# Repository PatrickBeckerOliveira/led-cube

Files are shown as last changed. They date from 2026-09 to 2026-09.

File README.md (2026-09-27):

# LED Cube 4×4×4 — ESP32-C3 + BLE

A 64-LED cube controlled by an ESP32-C3 SuperMini, two daisy-chained TPIC6B595 shift registers, and four layers switched by NPN-driven P-channel MOSFETs. Arduino firmware with BLE commands and five sequential animation effects.

## Firmware

Open `led_cube_ble/led_cube_ble.ino` in the Arduino IDE with the **esp32 board package by Espressif Systems** installed. Select the appropriate ESP32-C3 board (ESP32C3 Dev Module where applicable) and serial port. The code uses the BLE library included in the ESP32 package, along with `<atomic>`.

This version preserves the behavior of the animation code provided in the conversation. It has not been compiled or validated on hardware as part of this delivery; no specific ESP32 board package version has been pinned.

## Pin Mapping

| Function | GPIO |
|---|---:|
| TPIC SER IN / Data | 4 |
| TPIC SRCK / Clock | 5 |
| TPIC RCK / Latch | 6 |
| Layer 1 / NPN base | 7 |
| Layer 2 / NPN base | 8 |
| Layer 3 / NPN base | 9 |
| Layer 4 / NPN base | 10 |

Driving a layer GPIO high turns on the NPN transistor, which in turn switches on the P-channel MOSFET. A bit set to 1 in the TPIC activates the corresponding current-sinking output. The physical column order depends on the wiring.

## Using nRF Connect

1. Power on the board and connect to `Cubo_LED_4x4x4`.
2. Open service `6e400001-b5a3-f393-e0a9-e50e24dcca9e`.
3. Write UTF-8 text to characteristic `6e400002-b5a3-f393-e0a9-e50e24dcca9e`.

| Command | Action |
|---|---|
| `ON` or `1` | Start/restart the sequence |
| `OFF` or `0` | Turn off the cube |

The cube starts with all LEDs off when powered on. Disconnecting the app does not stop an ongoing animation; the device resumes advertising to allow reconnection. Commands do not require BLE authentication.

## Effects

1. Layers moving up and down.
2. Vertical columns lighting up in sequence.
3. Eight twinkling points.
4. Filling and emptying the cube layer by layer.
5. Three flashes followed by a pause.

The sequence repeats until `OFF` is received. Animation updates use `millis()`, and multiplexing uses `micros()`, with a nominal period of 2 ms per layer and a blanking interval of 30 µs. At most one layer is activated at a time. Timing and duration can be adjusted through the constants and the `updateAnimation()` function.

## Hardware Notes

- Cube supply: 5 V, with a common ground shared with the ESP. The power supply's current rating does not determine the current capacity of the SuperMini's PCB traces.
- GPIO8 and GPIO9 are boot strapping pins. The NPN base connections may interfere with startup, especially on GPIO9; using 10 kΩ resistors connected to the base showed no problems, lowering this value may cause issues.
- According to its datasheet, a TPIC6B595 powered at 5 V requires a minimum logic-high input of 0.85 × VCC = 4.25 V. Direct drive from 3.3 V GPIOs works but is not guaranteed; logic-level conversion should be implemented in the future.
- With 100 Ω column resistors and an LED forward voltage of approximately 3 V, the simplified estimate is 20 mA per LED and 320 mA for a full layer, plus the control electronics. Measure the actual current before sizing the power supply.

References: [TPIC6B595 — TI](https://www.ti.com/lit/ds/symlink/tpic6b595.pdf), [ESP32-C3 Boot Mode Selection — Espressif](https://docs.espressif.com/projects/esptool/en/latest/esp32c3/advanced-topics/boot-mode-selection.html).

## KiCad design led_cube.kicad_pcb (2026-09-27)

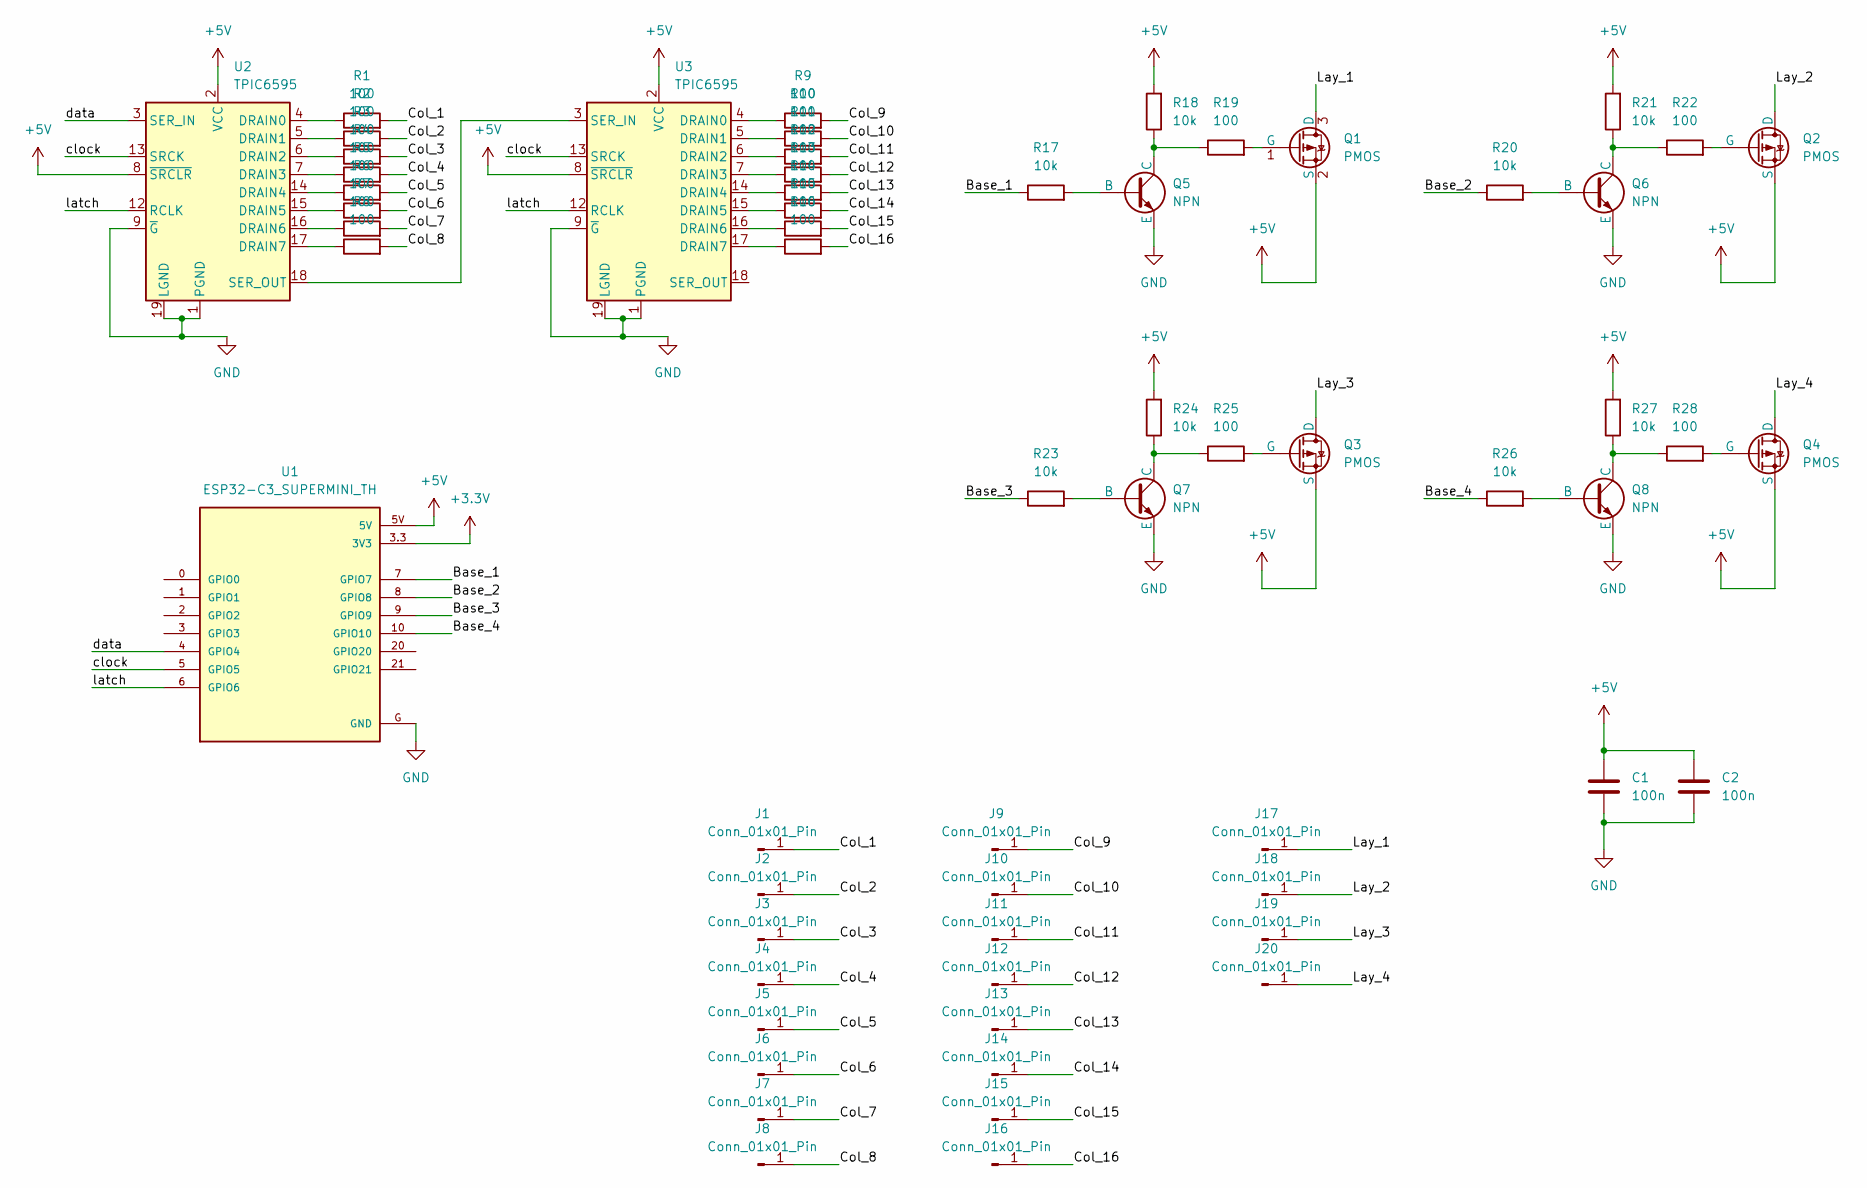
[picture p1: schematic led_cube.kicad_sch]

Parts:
C1, C2: 100n; C_Disc_D10.0mm_W2.5mm_P5.00mm
J1, J2, J3, J4, J5, J6, J7, J8, J9, J10, J11, J12, J13, J14, J15, J16, J17, J18, J19, J20: Conn_01x01_Pin; TestPoint_THTPad_3.0x3.0mm_Drill1.5mm
Q1, Q2, Q3, Q4: PMOS; SOT-23_Handsoldering
Q5, Q6, Q7, Q8: NPN; TO-92_HandSolder
R1, R2, R3, R4, R5, R6, R7, R8, R9, R10, R11, R12, R13, R14, R15, R16, R19, R22, R25, R28: 100; R_1206_3216Metric_Pad1.30x1.75mm_HandSolder
R17, R18, R20, R21, R23, R24, R26, R27: 10k; R_1206_3216Metric_Pad1.30x1.75mm_HandSolder
U1: ESP32-C3_SUPERMINI_TH; MODULE_ESP32-C3_SUPERMINI_TH
U2, U3: TPIC6595; CERDIP-20_W7.62mm_SideBrazed

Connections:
+3.3V: U1.3.3 (3V3)
+5V: C1.1, C2.1, Q1.2 (S), Q2.2 (S), Q3.2 (S), Q4.2 (S), R18.2, R21.2, R24.2, R27.2, U1.5V, U2.2 (VCC), U2.8 (~SRCLR), U3.2 (VCC), U3.8 (~SRCLR)
/Base_1: R17.1, U1.7 (GPIO7)
/Base_2: R20.1, U1.8 (GPIO8)
/Base_3: R23.1, U1.9 (GPIO9)
/Base_4: R26.1, U1.10 (GPIO10)
/Col_1: J1.1 (Pin_1_1), R1.2
/Col_2: J2.1 (Pin_1_1), R2.2
/Col_3: J3.1 (Pin_1_1), R3.2
/Col_4: J4.1 (Pin_1_1), R4.2
/Col_5: J5.1 (Pin_1_1), R5.2
/Col_6: J6.1 (Pin_1_1), R6.2
/Col_7: J7.1 (Pin_1_1), R7.2
/Col_8: J8.1 (Pin_1_1), R8.2
/Col_9: J9.1 (Pin_1_1), R9.2
/Col_10: J10.1 (Pin_1_1), R10.2
/Col_11: J11.1 (Pin_1_1), R11.2
/Col_12: J12.1 (Pin_1_1), R12.2
/Col_13: J13.1 (Pin_1_1), R13.2
/Col_14: J14.1 (Pin_1_1), R14.2
/Col_15: J15.1 (Pin_1_1), R15.2
/Col_16: J16.1 (Pin_1_1), R16.2
/Lay_1: J17.1 (Pin_1_1), Q1.3 (D)
/Lay_2: J18.1 (Pin_1_1), Q2.3 (D)
/Lay_3: J19.1 (Pin_1_1), Q3.3 (D)
/Lay_4: J20.1 (Pin_1_1), Q4.3 (D)
/clock: U1.5 (GPIO5), U2.13 (SRCK), U3.13 (SRCK)
/data: U1.4 (GPIO4), U2.3 (SER_IN)
/latch: U1.6 (GPIO6), U2.12 (RCLK), U3.12 (RCLK)
GND: C1.2, C2.2, Q5.3 (E), Q6.3 (E), Q7.3 (E), Q8.3 (E), U1.G (GND), U2.1 (PGND), U2.9 (~G), U2.10 (PGND), U2.11 (PGND), U2.19 (LGND), U2.20 (PGND), U3.1 (PGND), U3.9 (~G), U3.10 (PGND), U3.11 (PGND), U3.19 (LGND), U3.20 (PGND)
unnamed: Q1.1 (G), R19.2
unnamed: Q2.1 (G), R22.2
unnamed: Q3.1 (G), R25.2
unnamed: Q4.1 (G), R28.2
unnamed: Q5.2 (B), R17.2
unnamed: Q5.1 (C), R18.1, R19.1
unnamed: Q6.2 (B), R20.2
unnamed: Q6.1 (C), R21.1, R22.1
unnamed: Q7.2 (B), R23.2
unnamed: Q7.1 (C), R24.1, R25.1
unnamed: Q8.2 (B), R26.2
unnamed: Q8.1 (C), R27.1, R28.1
unnamed: R1.1, U2.4 (DRAIN0)
unnamed: R2.1, U2.5 (DRAIN1)
unnamed: R3.1, U2.6 (DRAIN2)
unnamed: R4.1, U2.7 (DRAIN3)
unnamed: R5.1, U2.14 (DRAIN4)
unnamed: R6.1, U2.15 (DRAIN5)
unnamed: R7.1, U2.16 (DRAIN6)
unnamed: R8.1, U2.17 (DRAIN7)
unnamed: U2.18 (SER_OUT), U3.3 (SER_IN)
unnamed: R9.1, U3.4 (DRAIN0)
unnamed: R10.1, U3.5 (DRAIN1)
unnamed: R11.1, U3.6 (DRAIN2)
unnamed: R12.1, U3.7 (DRAIN3)
unnamed: R13.1, U3.14 (DRAIN4)
unnamed: R14.1, U3.15 (DRAIN5)
unnamed: R15.1, U3.16 (DRAIN6)
unnamed: R16.1, U3.17 (DRAIN7)

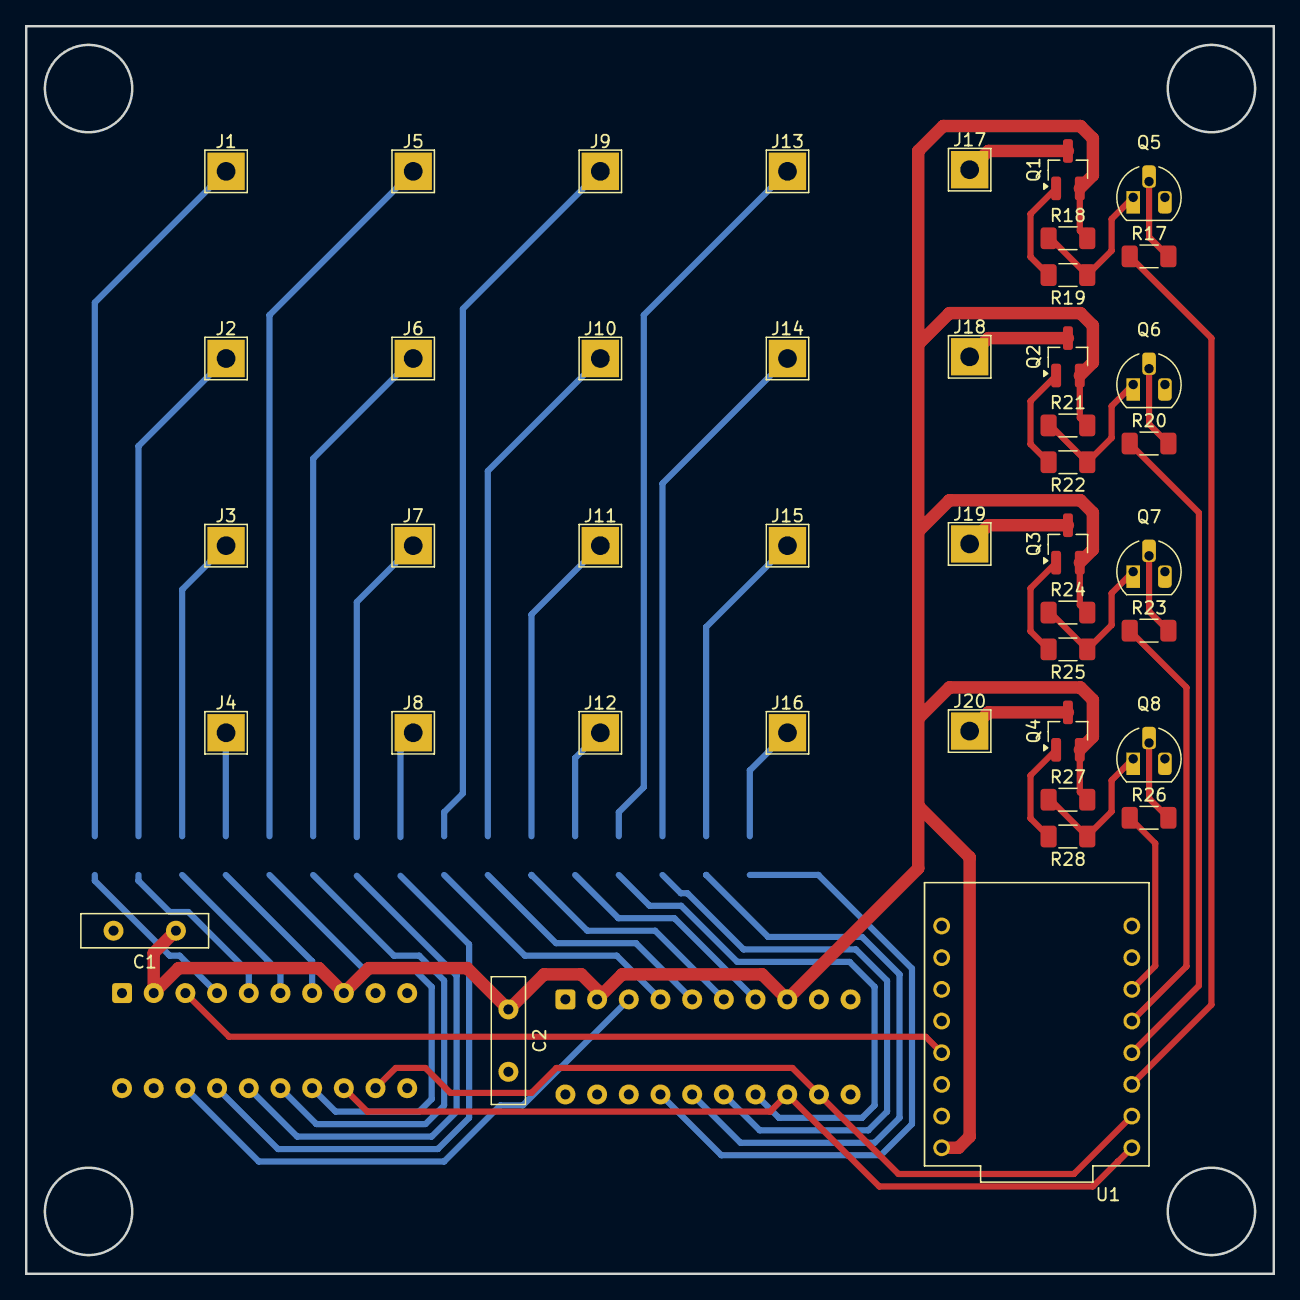
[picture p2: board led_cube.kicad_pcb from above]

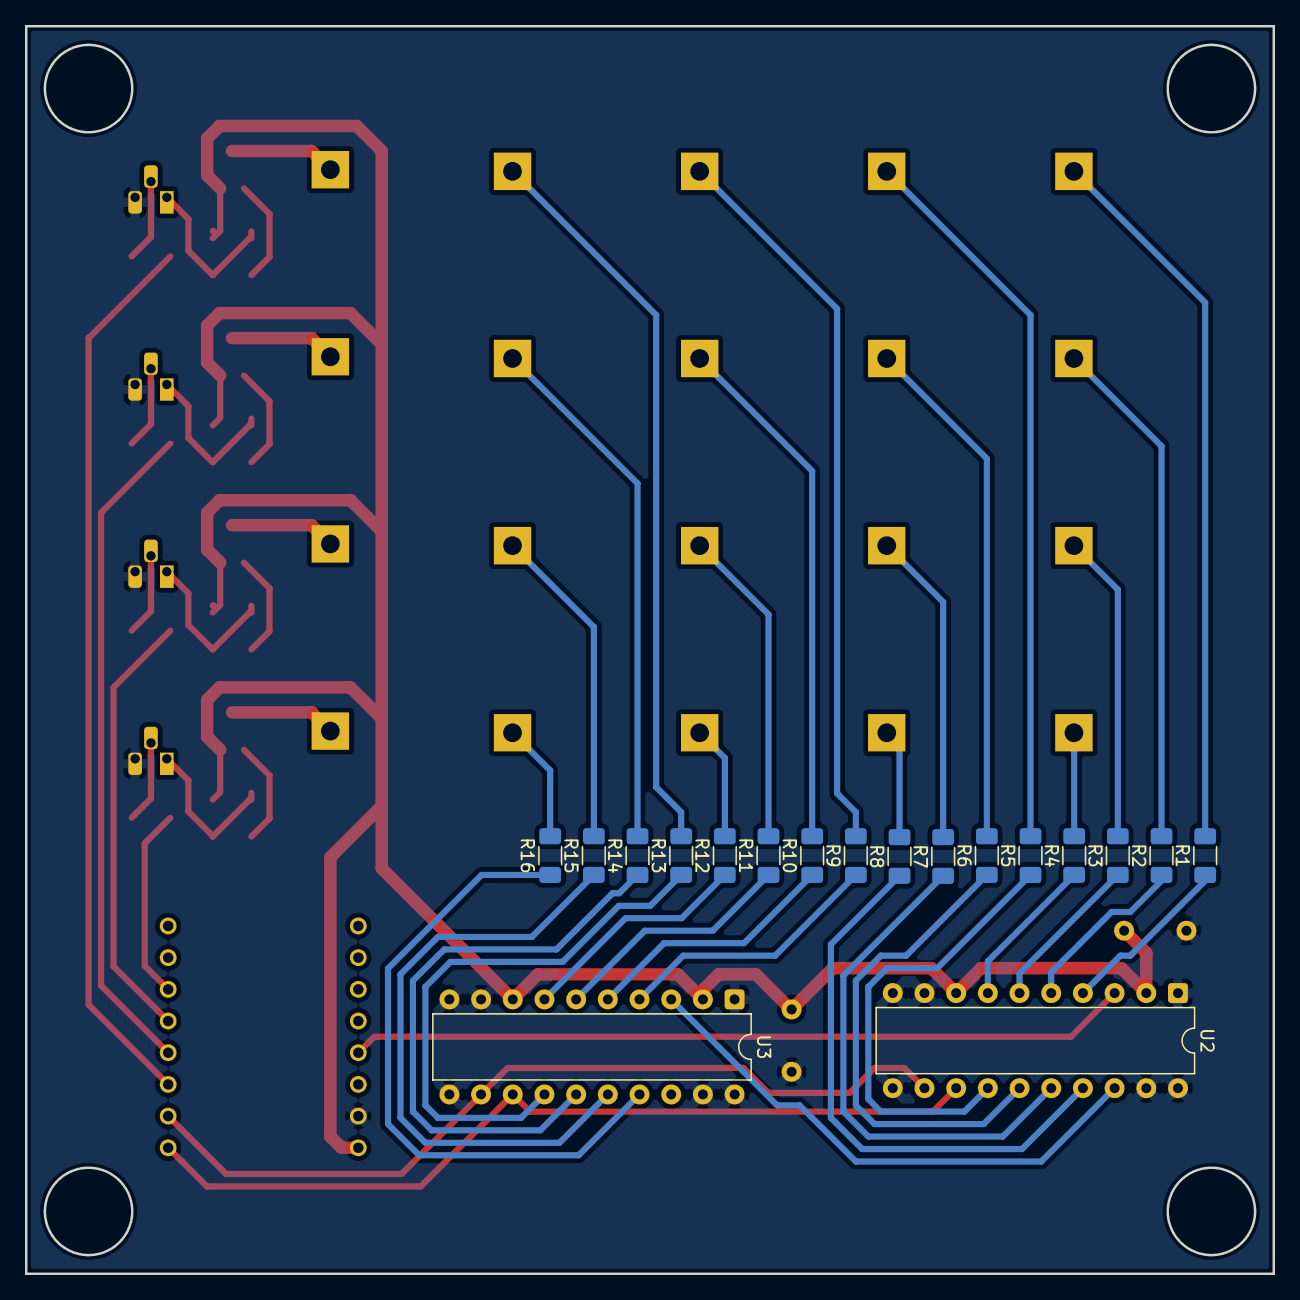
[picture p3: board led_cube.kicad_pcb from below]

Board: 2 copper layers, 100.0 x 100.0 mm, 61 parts (18 on the bottom side), 58 nets.

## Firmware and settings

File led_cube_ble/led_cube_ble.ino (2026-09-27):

#include <Arduino.h>
#include <BLEDevice.h>
#include <BLEServer.h>
#include <BLEUtils.h>
#include <atomic>

// Circuit pins for the ESP32-C3 and two TPIC6B595 shift registers.
constexpr uint8_t PIN_DATA = 4;
constexpr uint8_t PIN_CLOCK = 5;
constexpr uint8_t PIN_LATCH = 6;
constexpr uint8_t PIN_LAYER[4] = {7, 8, 9, 10};
constexpr uint32_t LAYER_TIME_US = 2000;
constexpr uint32_t BLANK_TIME_US = 30;

#define SERVICE_UUID "6e400001-b5a3-f393-e0a9-e50e24dcca9e"
#define COMMAND_UUID "6e400002-b5a3-f393-e0a9-e50e24dcca9e"

enum Command { CMD_NONE, CMD_ON, CMD_OFF };
std::atomic<int> pendingCommand{CMD_NONE};
std::atomic<bool> restartAdvertising{false};
bool cubeEnabled = false;

// One element per layer; each bit represents a column.
uint16_t frame[4] = {0, 0, 0, 0};
uint8_t scanLayer = 0;
uint32_t lastScanUs = 0;
uint8_t effect = 0;
uint32_t effectStartMs = 0;
uint32_t lastAnimationStep = UINT32_MAX;
const uint32_t EFFECT_DURATION_MS[] = {4200, 4800, 4000, 1800, 1500};
constexpr uint8_t EFFECT_COUNT =
  sizeof(EFFECT_DURATION_MS) / sizeof(EFFECT_DURATION_MS[0]);

void disableLayers() {
  for (uint8_t pin : PIN_LAYER) digitalWrite(pin, LOW);
}

void setColumns(uint16_t columns) {
  digitalWrite(PIN_LATCH, LOW);
  shiftOut(PIN_DATA, PIN_CLOCK, MSBFIRST, highByte(columns));
  shiftOut(PIN_DATA, PIN_CLOCK, MSBFIRST, lowByte(columns));
  digitalWrite(PIN_LATCH, HIGH);
}

void clearFrame() {
  for (uint8_t layer = 0; layer < 4; layer++) frame[layer] = 0;
}

void fillFrame() {
  for (uint8_t layer = 0; layer < 4; layer++) frame[layer] = 0xFFFF;
}

void turnCubeOff() {
  disableLayers();
  setColumns(0);
  clearFrame();
}

void refreshCube() {
  const uint32_t nowUs = micros();
  if (nowUs - lastScanUs < LAYER_TIME_US) return;
  lastScanUs = nowUs;
  // Blank the outputs before switching layers to prevent overlap.
  disableLayers();
  setColumns(0);
  delayMicroseconds(BLANK_TIME_US);
  const uint16_t columns = frame[scanLayer];
  setColumns(columns);
  if (columns != 0) digitalWrite(PIN_LAYER[scanLayer], HIGH);
  scanLayer = (scanLayer + 1) % 4;
}

void updateAnimation(uint32_t nowMs) {
  uint32_t elapsed = nowMs - effectStartMs;
  if (elapsed >= EFFECT_DURATION_MS[effect]) {
    effect = (effect + 1) % EFFECT_COUNT;
    effectStartMs = nowMs;
    lastAnimationStep = UINT32_MAX;
    elapsed = 0;
    clearFrame();
  }
  uint32_t step;
  switch (effect) {
    case 0: { // Layers move up and down.
      step = elapsed / 175;
      if (step == lastAnimationStep) return;
      lastAnimationStep = step;
      const uint8_t sequence[] = {0, 1, 2, 3, 2, 1};
      clearFrame();
      frame[sequence[step % 6]] = 0xFFFF;
      break;
    }
    case 1: { // A vertical column moves through all 16 positions.
      step = elapsed / 150;
      if (step == lastAnimationStep) return;
      lastAnimationStep = step;
      const uint8_t column = step % 16;
      const uint16_t mask = uint16_t(1U << column);
      for (uint8_t layer = 0; layer < 4; layer++) frame[layer] = mask;
      break;
    }
    case 2: { // Eight twinkling points.
      step = elapsed / 100;
      if (step == lastAnimationStep) return;
      lastAnimationStep = step;
      clearFrame();
      uint8_t count = 0;
      while (count < 8) {
        const uint8_t layer = random(4);
        const uint8_t column = random(16);
        const uint16_t mask = uint16_t(1U << column);
        if ((frame[layer] & mask) == 0) {
          frame[layer] |= mask;
          count++;
        }
      }
      break;
    }
    case 3: { // Fill and empty the cube.
      step = elapsed / 200;
      if (step == lastAnimationStep) return;
      lastAnimationStep = step;
      const uint8_t levels[] = {0, 1, 2, 3, 4, 3, 2, 1, 0};
      const uint8_t count = levels[step % 9];
      clearFrame();
      for (uint8_t layer = 0; layer < count; layer++) frame[layer] = 0xFFFF;
      break;
    }
    case 4: { // Three flashes followed by a pause.
      step = elapsed / 150;
      if (step == lastAnimationStep) return;
      lastAnimationStep = step;
      if (step < 6 && (step % 2 == 0)) fillFrame();
      else clearFrame();
      break;
    }
  }
}

class CommandCallbacks : public BLECharacteristicCallbacks {
  void onWrite(BLECharacteristic *characteristic) override {
    String command = String(characteristic->getValue().c_str());
    command.trim();
    command.toUpperCase();
    if (command == "ON" || command == "1") pendingCommand.store(CMD_ON);
    else if (command == "OFF" || command == "0") pendingCommand.store(CMD_OFF);
  }
};

class ServerCallbacks : public BLEServerCallbacks {
  void onDisconnect(BLEServer *server) override {
    restartAdvertising.store(true);
  }
};

void setup() {
  Serial.begin(115200);
  for (uint8_t pin : PIN_LAYER) {
    digitalWrite(pin, LOW);
    pinMode(pin, OUTPUT);
  }
  pinMode(PIN_DATA, OUTPUT);
  pinMode(PIN_CLOCK, OUTPUT);
  pinMode(PIN_LATCH, OUTPUT);
  digitalWrite(PIN_DATA, LOW);
  digitalWrite(PIN_CLOCK, LOW);
  digitalWrite(PIN_LATCH, LOW);
  turnCubeOff();
  BLEDevice::init("Cubo_LED_4x4x4");
  BLEServer *server = BLEDevice::createServer();
  server->setCallbacks(new ServerCallbacks());
  BLEService *service = server->createService(SERVICE_UUID);
  BLECharacteristic *commandCharacteristic = service->createCharacteristic(
    COMMAND_UUID,
    BLECharacteristic::PROPERTY_WRITE | BLECharacteristic::PROPERTY_WRITE_NR
  );
  commandCharacteristic->setCallbacks(new CommandCallbacks());
  service->start();
  BLEAdvertising *advertising = BLEDevice::getAdvertising();
  advertising->addServiceUUID(SERVICE_UUID);
  advertising->start();
  Serial.println("Cubo pronto. Envie ON ou OFF via BLE.");
}

void loop() {
  if (restartAdvertising.exchange(false)) BLEDevice::startAdvertising();
  const int command = pendingCommand.exchange(CMD_NONE);
  if (command == CMD_ON) {
    turnCubeOff();
    effect = 0;
    effectStartMs = millis();
    lastAnimationStep = UINT32_MAX;
    scanLayer = 0;
    lastScanUs = micros() - LAYER_TIME_US;
    cubeEnabled = true;
    Serial.println("Animacoes iniciadas.");
  } else if (command == CMD_OFF) {
    cubeEnabled = false;
    turnCubeOff();
    Serial.println("Cubo desligado.");
  }
  if (!cubeEnabled) {
    delay(1);
    return;
  }
  updateAnimation(millis());
  refreshCube();
}

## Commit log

2026-09-27 Add BLE-controlled LED cube animations
2026-09-27 Document wiring, BLE commands and animation effects
2026-09-27 Uploading schematic and PCB files
    [led_cube.kicad_pcb, led_cube.kicad_sch]
